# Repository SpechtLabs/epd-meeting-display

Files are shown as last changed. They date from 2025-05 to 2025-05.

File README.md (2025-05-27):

# ESP32 based E-Paper Meeting Room Display

If you work from home frequently and you have kids or a spouse working part-time you might find it difficult to signal if you're in a meeting right now or not.

While there might be "busy lights" available for purchase from Amazon to signal if you're available or not, I thought to myself "surely I could build that myself?".

And long and behold, my low-power meeting room display using a wifi-enabled ESP32 microcontroller and a 7.5" E-Paper display was born. It fetches Calendar data via [CalendarAPI](https://github.com/SpechtLabs/CalendarAPI) and not only prints an indicator if you're currently in a meeting or not, but it also shows a small overview of your schedule for the day, which I found super usefull. As soon as I enter my office, I already have an overview of my meeting schedule for the day.

The display also supports custom status messages and comes with an [HomeAssistant Integration](https://calendarapi.specht-labs.de/guide/home_assistant.html) so you can set custom status messages via HomeAssistant. In my case I use this if the resin 3D printer is running to display a biohazard icon and a status message reminding me of wearing a respirator.

## Credits

Huge thanks to [Luke Marzen](https://github.com/lmarzen) and his [ESP32 E-Paper Weather Display](https://github.com/lmarzen/esp32-weather-epd) project. It was a huge inspiration for me, and proved to be a very good starting point for me to base my display on.

## Required Components

| Component Type  | Component | Notes |
| --- | --- | --- |
| ESP32 | FireBeetle 2 ESP32-E | Features low-power design, USB-C, and battery management. |
| E-Paper Display | See [Panel Support](#panel-support). | See [Panel Support](#panel-support). |
| Adapter Board | DESPI-C02 | |
| Battery | 3.7V LiPo w/ JST-PH2.0 connector | Any capacity (e.g., 5000mAh for 6+ months runtime) |
| Enclosure | | See [Enclosure Options](#enclosure). |

Other items needed:

- Wires ("Jumper Wires" if looking to minimize/avoid soldering).
- Solder Iron + Solder
- Linux, Windows, or MacOS computer (used to configure and install ESP32 firmware).

### Panel Support

Refrain from using Waveshare Displays and jump straight to Good Display with a DESPI-C02 adapter board
Good Display make equivalent panels. Either variant will work.

| Panel | Resolution | Colors | Link |
| --- | --- | --- | --- |
| Good Display 7.5in e-paper (GDEY075T7) | 800x480px  | Black/White | [Good Display](https://www.good-display.com/product/396.html) |
| Good Display 7.5in e-paper (GDEY075Z08) | 800x480px  | Red/Black/White | [Good Display](https://www.good-display.com/product/394.html) |
| Good Display 7.3in e-paper (EOL) (GDEY073D46) | 800x480px  | 7-Color | [Good Display](https://www.good-display.com/product/442.html) |

This software has limited support for accent colors. E-paper panels with additional colors tend to have longer refresh times, which will reduce battery life.

### Enclosure

I designed a simple enclosure with a sliding mechanism in [OnShape](https://cad.onshape.com/documents/a085c42da6149c918189f270/w/8138a9f47d2dacfe28cef74e/e/b4459c145c0eb402d3061e76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). You can also download the [STL files here](./stl/).

Please feel free to improve on the enclosure and contribute improvements back.

## Setup Guide

### Wiring

> **Warning**
> The polarity of JST-PH2.0 connectors is not standardized! You may need to swap the order of the wires in the connector.

The battery can be charged by plugging the FireBeetle ESP32 into the wall via the USB-C connector while the battery is plugged into the ESP32's JST connector.

> **Important**
> The DESPI-C02 adapter has one physical switch that MUST be set correctly for the display to work.
>
> - RESE: Set switch to position 0.47.

Cut the low power pad for even longer battery life.

- From <https://wiki.dfrobot.com/FireBeetle_Board_ESP32_E_SKU_DFR0654>

  > Low Power Pad: This pad is specially designed for low power consumption. It is connected by default. You can cut off the thin wire in the middle with a knife to disconnect it. After disconnection, the static power consumption can be reduced by 500 μA. The power consumption can be reduced to 13 μA after controlling the maincontroller enter the sleep mode through the program. Note: when the pad is disconnected, you can only drive RGB LED light via the USB Power supply.

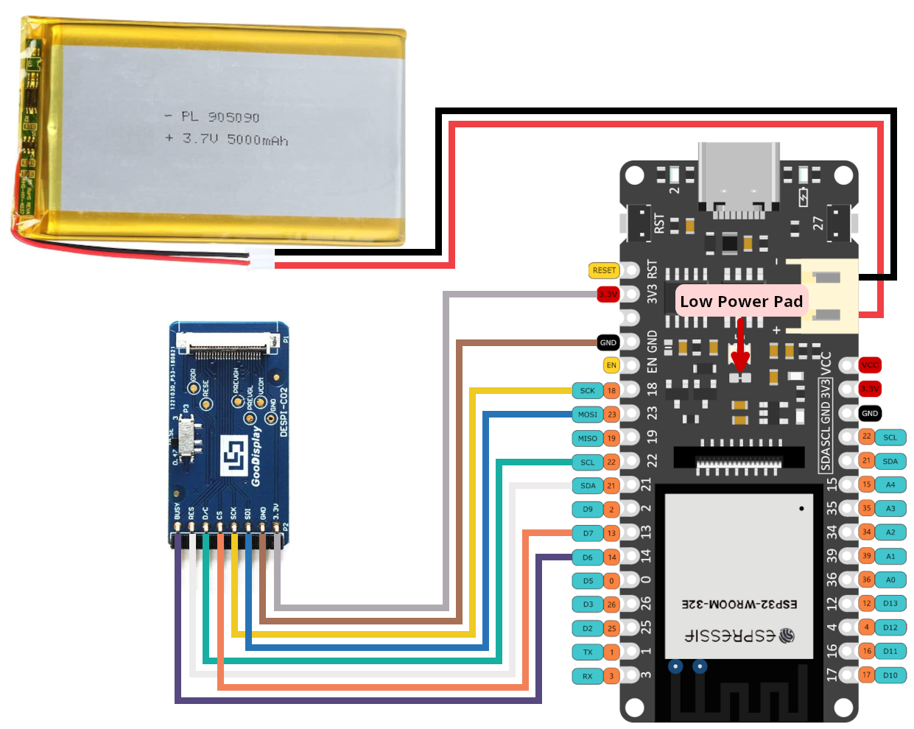
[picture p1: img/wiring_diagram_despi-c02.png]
Wiring diagram with DESPI-C02 driver board


### Configuration, Compilation, and Upload

[PlatformIO](https://platformio.org/) for VSCode is used for managing dependencies, code compilation, and uploading to ESP32.

1. Clone this repository or download and extract the `.zip`.
2. Install VSCode.
3. Follow [these instructions](https://platformio.org/install/ide?install=vscode) to install the PlatformIO extension for VSCode
4. Open the project in VSCode.
   1. `File` > `Open Folder...`
   2. Navigate to this project
5. Configure Options.
   - Configuration options are located in [config.h](include/config.h)
   - Important settings to configure in [config.h](include/config.h):
     - WiFi credentials (ssid, password)
     - [CalendarAPI](https://github.com/SpechtLabs/CalendarAPI) Endpoint
     - Timezone
     - Time and date formats
6. Build and Upload Code.
   1. Connect ESP32 to your computer via USB.
   2. Click the upload arrow along the bottom of the VSCode window. (Should say "PlatformIO: Upload" if you hover over it.)
      - PlatformIO will automatically download the required third-party libraries, compile, and upload the code. :)
      - You will only see this if you have the PlatformIO extension installed.
      - If using a FireBeetle 2 ESP32-E and you receive the error `Wrong boot mode detected (0x13)! The chip needs to be in download mode.` unplug the power from the board, connect GPIO0 ([labeled 0/D5](https://wiki.dfrobot.com/FireBeetle_Board_ESP32_E_SKU_DFR0654#target_5)) to GND, and power it back up to put the board in download mode.
      - If you are getting other errors during the upload process, you may need to install drivers to allow you to upload code to the ESP32.

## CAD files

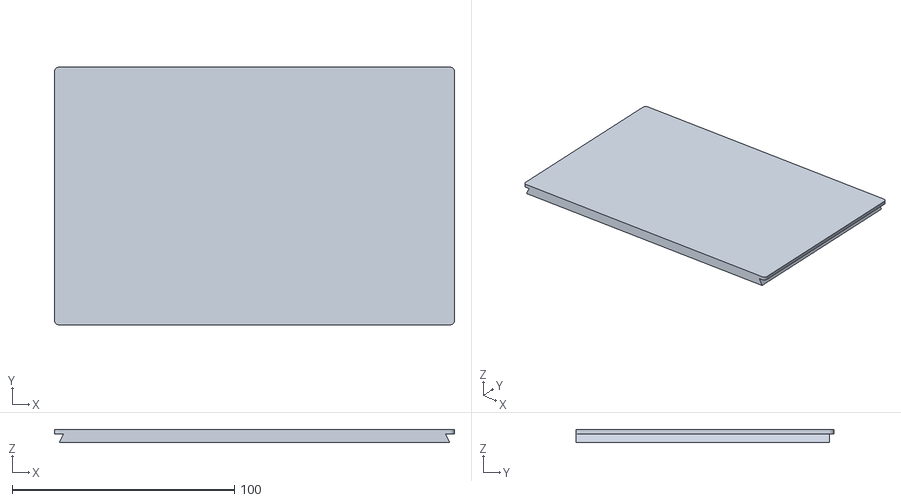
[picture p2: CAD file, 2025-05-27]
stl/backplate.stl
180.0 x 116.0 x 6.00

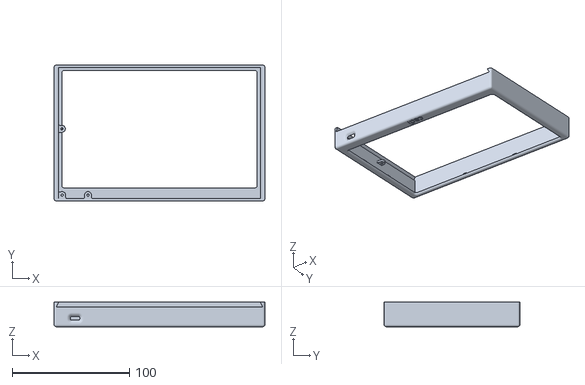
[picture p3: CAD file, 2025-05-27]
stl/case.stl
180.0 x 116.0 x 21.0

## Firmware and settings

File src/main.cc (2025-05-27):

#include <Arduino.h>
#include <Preferences.h>
#include <time.h>
#include <WiFi.h>
#include <WiFiClient.h>
#include <Wire.h>
#include <ctime>
#include <string>
#include <sstream>

#include "config.h"
#include "utils.h"
#include "client/calendar_client.h"
#include "components/display_config.h"

#include "display.h"

Preferences prefs;
calendar_client::CalendarClient calClient(API_ENDPOINT, API_ENDPOINT_PORT);

#if defined(DISP_3C) || defined(DISP_7C)
Display epd(PIN_EPD_PWR, PIN_EPD_SCK, PIN_EPD_MISO, PIN_EPD_MOSI, PIN_EPD_CS, PIN_EPD_DC, PIN_EPD_RST, PIN_EPD_BUSY, &calClient, ACCENT_COLOR);
#else
Display epd(PIN_EPD_PWR, PIN_EPD_SCK, PIN_EPD_MISO, PIN_EPD_MOSI, PIN_EPD_CS, PIN_EPD_DC, PIN_EPD_RST, PIN_EPD_BUSY, &calClient);
#endif

// Put esp32 into ultra low-power deep sleep (<11μA).
void beginDeepSleep(unsigned long startTime)
{
	killWiFi();

	tm timeInfo = {};
	// only call getLocalTime if we havent gotten the ntp time yet
	if (!getLocalTime(&timeInfo))
	{
		Serial.println("Failed to synchronize time before deep-sleep, referencing older time.");
	}

	time_t now = mktime(&timeInfo);

	int sleepSeconds = SLEEP_DURATION * 60; // SLEEP_DURATION is in minutes, multiply by 60

	// Sleep duration is until the end of this meeting, or till the beginning of the next meeting
	const calendar_client::CalendarEntry *currEvent = calClient.getCurrentEvent(now, false);

	if (currEvent != NULL)
	{
		sleepSeconds = difftime(currEvent->getEnd(), now); // calculate the minutes until the event ends
#if DEBUG_LEVEL >= 1
		Serial.println("[debug] sleeping till end of this event: " + currEvent->getTitle() + " (" + sleepSeconds + "s)");
#endif
	}
	else
	{
		const calendar_client::CalendarEntry *nextEvent = calClient.getNextEvent(now);
		if (nextEvent != NULL)
		{
			sleepSeconds = difftime(nextEvent->getStart(), now); // calculate the minutes until the next event starts
#if DEBUG_LEVEL >= 1
			Serial.println("[debug] sleeping till start of next event: " + nextEvent->getTitle() + " (" + sleepSeconds + "s)");
#endif
		}
	}

	// if we sleep for more than SLEEP_DURATION, wake up a bit earlier,
	// to check for potential new calendar invites
	if (sleepSeconds > SLEEP_DURATION * 60)
	{
		sleepSeconds = SLEEP_DURATION * 60;
	}

	// add extra delay to compensate for esp32's with fast RTCs.
	sleepSeconds += 10ULL;

#if DEBUG_LEVEL >= 1
	printHeapUsage();
#endif

	Serial.println("\nAwake for " + String((millis() - startTime) / 1000.0, 3) + "s");
	Serial.println("Entering deep sleep for " + String(sleepSeconds) + "s");
	esp_sleep_enable_timer_wakeup(sleepSeconds * 1000000ULL);

	esp_deep_sleep_start();
}

// Program entry point.
void setup()
{
	unsigned long startTime = millis();
	Serial.begin(115200);

#if DEBUG_LEVEL >= 1
	printHeapUsage();
#endif

	disableBuiltinLED();

	// Open namespace for read/write to non-volatile storage
	prefs.begin(NVS_NAMESPACE, false);

	uint32_t batteryVoltage = readBatteryVoltage();
	Serial.print("Battery voltage");
	Serial.println(": " + String(batteryVoltage) + "mv");

	// When the battery is low, the display should be updated to reflect that, but
	// only the first time we detect low voltage. The next time the display will
	// refresh is when voltage is no longer low. To keep track of that we will
	// make use of non-volatile storage.
	bool lowBat = prefs.getBool("lowBat", false);

	// low battery, deep sleep now
	if (batteryVoltage <= LOW_BATTERY_VOLTAGE)
	{
		if (lowBat == false)
		{ // battery is now low for the first time
			prefs.putBool("lowBat", true);
			prefs.end();
			epd.error("battery_alert_90deg", "Low Battery");
		}

		// critically low battery
		// don't set esp_sleep_enable_timer_wakeup();
		// We won't wake up again until someone manually presses the RST button.
		if (batteryVoltage <= CRIT_LOW_BATTERY_VOLTAGE)
		{
			Serial.println("Critically low battery voltage!");
			Serial.println("Hibernating without wake time!");
		}
		// very low battery
		else if (batteryVoltage <= VERY_LOW_BATTERY_VOLTAGE)
		{
			Serial.println("Very low battery voltage!");
			Serial.print("Entering deep sleep for " + String(VERY_LOW_BATTERY_SLEEP_INTERVAL) + "min");
			esp_sleep_enable_timer_wakeup(VERY_LOW_BATTERY_SLEEP_INTERVAL * 60ULL * 1000000ULL);
		}
		// low battery
		else
		{
			Serial.println("Low battery voltage!");
			Serial.println("Entering deep sleep for " + String(LOW_BATTERY_SLEEP_INTERVAL) + "min");
			esp_sleep_enable_timer_wakeup(LOW_BATTERY_SLEEP_INTERVAL * 60ULL * 1000000ULL);
		}

		esp_deep_sleep_start();
	}

	// battery is no longer low, reset variable in non-volatile storage
	if (lowBat == true)
	{
		prefs.putBool("lowBat", false);
	}

	// All data should have been loaded from NVS. Close filesystem.
	prefs.end();

	tm timeInfo = {};

	// START WIFI
	wl_status_t wifiStatus = startWiFi();

	// WiFi Connection Failed
	if (wifiStatus != WL_CONNECTED)
	{

		if (wifiStatus == WL_NO_SSID_AVAIL)
		{
			epd.error("wifi_x", "Network Not Available");
		}
		else
		{
			epd.error("wifi_x", "WiFi Connection Failed");
		}

		beginDeepSleep(startTime);
	}

	// TIME SYNCHRONIZATION
	configTzTime(TIMEZONE, NTP_SERVER_1, NTP_SERVER_2);
	bool timeConfigured = getNtpTime(&timeInfo);
	if (!timeConfigured)
	{
		epd.error("wi_time_4", "Time Synchronization Failed");
		beginDeepSleep(startTime);
	}

	int httpStatus = calClient.fetchCustomStatus();
	if (httpStatus != HTTP_CODE_OK && httpStatus != HTTP_CODE_GONE)
	{
		std::stringstream ss;
		ss << "Fetching status failed";

		epd.error("wi_cloud_down", ss.str().c_str(), calendar_client::CalendarClient::getHttpResponsePhrase(httpStatus), mktime(&timeInfo));
		beginDeepSleep(startTime);
	}

	const calendar_client::CustomStatus *stat = calClient.getCustomStatus();
	if (stat != NULL && !stat->getTitle().isEmpty())
	{
		epd.fullPageStatus(stat->getIcon(), stat->getIconSize(), stat->getTitle(), stat->getDescription(), mktime(&timeInfo));
		beginDeepSleep(startTime);
	}

	httpStatus = calClient.fetchCalendar();
	if (httpStatus != HTTP_CODE_OK && httpStatus != HTTP_CODE_GONE)
	{
		std::stringstream ss;
		ss << "Fetching calendar failed";

		epd.error("wi_cloud_down", ss.str().c_str(), calendar_client::CalendarClient::getHttpResponsePhrase(httpStatus), mktime(&timeInfo));
		beginDeepSleep(startTime);
	}

	epd.render(mktime(&timeInfo));
	beginDeepSleep(startTime);
}

// This will never run
void loop()
{
}

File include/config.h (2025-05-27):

#pragma once

// WIFI
#define WIFI_SSID "<your_wifi_ssid>"
#define WIFI_PASSWORD "<your_wifi_password>"

// API
#define API_ENDPOINT "<your_api_endpoint>" // e.g. "homeassistant.local"
#define API_ENDPOINT_PORT 8099
#define API_ENDPOINT_FETCH_CALENDAR "<your_calendar_name>" // e.g. "work" or "home" or "all" to fetch all calendars

// Sleep duration in minutes. (aka how often esp32 will wake for an update)
#define SLEEP_DURATION 15 // minutes

// Display Strings
// This is usefull for localization and translation.
// If you want to change the language, you can do so by changing the
// TXT_... defines below.
#define TXT_PAST_EVENTS "past events"
#define TXT_UPCOMING_EVENTS "upcoming events"
#define TXT_UNTIL "until"
#define TXT_FREE "free"

// E-PAPER PANEL
// This project supports the following E-Paper panels:
//   DISP_BW  - 7.5in e-Paper (v2)      800x480px  Black/White
//   DISP_3C  - 7.5in e-Paper (B)       800x480px  Red/Black/White
//   DISP_7C  - 7.3in ACeP e-Paper (F)  800x480px  7-Color
// Uncomment the macro that identifies your physical panel.
#define DISP_BW
// #define DISP_3C
// #define DISP_7C

// DEBUG
//   If defined, enables increase verbosity over the serial port.
//   level 0: basic status information, assists troubleshooting (default)
//   level 1: increased verbosity for debugging
//   level 2: print api responses and verbose info to serial monitor
//   level 3: print display_buffer drawings (very noisy)
//   level 4: draw boundaries on draws
#define DEBUG_LEVEL 1

// TIME
// For list of time zones see
// https://github.com/nayarsystems/posix_tz_db/blob/master/zones.csv
#define TIMEZONE "CET-1CEST,M3.5.0,M10.5.0/3"

// Time format used when displaying sunrise/set times. (Max 11 characters)
// For more information about formatting see
// https://man7.org/linux/man-pages/man3/strftime.3.html
#define TIME_FORMAT "%H:%M" // 24-hour ex: 01:23   23:00

// Time format used when displaying axis labels. (Max 11 characters)
// For more information about formatting see
// https://man7.org/linux/man-pages/man3/strftime.3.html
#define HOUR_FORMAT "%H" // 24-hour ex: 01   23

// Date format used when displaying date in top-right corner.
// For more information about formatting see
// https://man7.org/linux/man-pages/man3/strftime.3.html
#define DATE_FORMAT "%a, %B %e" // ex: Sat, January 1

// Date/Time format used when displaying the last refresh time along the bottom
// of the screen.
// For more information about formatting see
// https://man7.org/linux/man-pages/man3/strftime.3.html
#define REFRESH_TIME_FORMAT "%e.%m.%Y %H:%M"

// NON-VOLATILE STORAGE (NVS) NAMESPACE
#define NVS_NAMESPACE "meeting_epd"

#ifdef DISP_BW
#define INVERT_AS_ACCENT true
#else
#define INVERT_AS_ACCENT false
#define ACCENT_COLOR Color::Red
#endif

// PINS
// The configuration below is intended for use with the project's official
// wiring diagrams using the FireBeetle 2 ESP32-E microcontroller board.
//
// Note: LED_BUILTIN pin will be disabled to reduce power draw.  Refer to your
//       board's pinout to ensure you avoid using a pin with this shared
//       functionality.
//
// ADC pin used to measure battery voltage
#define PIN_BAT_ADC A2 // A0 for micro-usb firebeetle

// Pins for E-Paper Driver Board
#define PIN_EPD_BUSY 14 // 5 for micro-usb firebeetle
#define PIN_EPD_CS 13
#define PIN_EPD_RST 21
#define PIN_EPD_DC 22
#define PIN_EPD_SCK 18
#define PIN_EPD_MISO 19 // 19 Master-In Slave-Out not used, as no data from display
#define PIN_EPD_MOSI 23
#define PIN_EPD_PWR 26 // Irrelevant if directly connected to 3.3V

// HTTP
// The following errors are likely the result of insuffient http client tcp timeout:
//   -1   Connection Refused
//   -11  Read Timeout
//   -258 Deserialization Incomplete Input
#define HTTP_CLIENT_TCP_TIMEOUT 1000 // ms

// ms, WiFi connection timeout.
#define WIFI_TIMEOUT 10000
// Number of times to retry connecting to WiFi or fetching the API before giving up.
#define RETRY_COUNT 10

// NTP_SERVER_1 is the primary time server, while NTP_SERVER_2 is a fallback.
// pool.ntp.org will find the closest available NTP server to you.
#define NTP_SERVER_1 "pool.ntp.org"
#define NTP_SERVER_2 "time.nist.gov"

// If you encounter the 'Failed To Fetch The Time' error, try increasing
// NTP_TIMEOUT or select closer/lower latency time servers.
#define NTP_TIMEOUT 20000 // ms
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

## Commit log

2026-10-08 chore(deps): update dependency jdx/mise to v2026.10.4 (#19)
    This PR contains the following updates:
    | Package | Update | Change | Pending |
    |---|---|---|---|
    | [jdx/mise](https://redirect.github.com/jdx/mise) | patch | `2026.10.3`
    → `2026.10.4` | `2026.10.5` |
    ---
    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
2026-10-10 chore(deps): update dependency jdx/mise to v2026.10.5 (#22)
    | [jdx/mise](https://redirect.github.com/jdx/mise) | patch | `2026.10.4`
    → `2026.10.5` | `2026.10.7` (+1) |
    ### Release Notes
    <details>
    <summary>jdx/mise (jdx/mise)</summary>
    ###
    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
2026-10-10 chore(deps): update dependency python to v3.15.0 (#21)
    | Package | Type | Update | Change |
    | [python](https://redirect.github.com/python/cpython) | tools | minor |
    `3.14.8` → `3.15.0` |
    <summary>python/cpython (python)</summary>
    [`v3.15.0`](https://redirect.github.com/python/cpython/compare/v3.14.8...v3.15.0rc2)
    [Compare
    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
2026-10-10 chore(deps): update dependency jdx/mise to v2026.10.6 (#24)
    | [jdx/mise](https://redirect.github.com/jdx/mise) | patch | `2026.10.5`
    → `2026.10.6` | `2026.10.7` |
    [`v2026.10.6`](https://redirect.github.com/jdx/mise/blob/HEAD/CHANGELOG.md#2026106---2026-10-09)
    Source](https://redirect.github.com/jdx/mise/compare/vfox-v2026.10.5...vfox-v2026.10.6)
    ##### 🚀 Features
    - **(bootstrap)** offer to install git and ssh before cloning a
    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
2026-10-11 chore(deps): update dependency jdx/mise to v2026.10.7 (#25)
    | Package | Update | Change |
    |---|---|---|
    | [jdx/mise](https://redirect.github.com/jdx/mise) | patch | `2026.10.6`
    → `2026.10.7` |
    [`v2026.10.7`](https://redirect.github.com/jdx/mise/blob/HEAD/CHANGELOG.md#2026107---2026-10-09)
    Source](https://redirect.github.com/jdx/mise/compare/vfox-v2026.10.6...vfox-v2026.10.7)
    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
2026-10-13 chore(deps): update dependency jdx/mise to v2026.10.8 (#26)
    | [jdx/mise](https://redirect.github.com/jdx/mise) | patch | `2026.10.7`
    → `2026.10.8` |
    [`v2026.10.8`](https://redirect.github.com/jdx/mise/blob/HEAD/CHANGELOG.md#2026108---2026-10-11)
    Source](https://redirect.github.com/jdx/mise/compare/vfox-v2026.10.7...vfox-v2026.10.8)
    - **(runtime-symlinks)** add a global link to the version global config
    selects by [@&#8203;jdx](https://redirect.github.com/jdx) in
    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
2026-10-14 chore(deps): update dependency jdx/mise to v2026.10.9 (#29)
    | [jdx/mise](https://redirect.github.com/jdx/mise) | patch | `2026.10.8`
    → `2026.10.9` | `2026.10.10` |
    <summary>jdx/mise</summary>
    [`v2026.10.9`](https://redirect.github.com/jdx/mise/blob/HEAD/CHANGELOG.md#2026109---2026-10-13)
    Source](https://redirect.github.com/jdx/mise/compare/vfox-v2026.10.8...vfox-v2026.10.9)
    - **(bootstrap)** add apt repositories and PPAs with
    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
2026-10-15 chore(deps): update dependency jdx/mise to v2026.10.10 (#30)
    | [jdx/mise](https://redirect.github.com/jdx/mise) | patch | `2026.10.9`
    → `2026.10.10` | `2026.10.11` |
    [`v2026.10.10`](https://redirect.github.com/jdx/mise/blob/HEAD/CHANGELOG.md#20261010---2026-10-14)
    Source](https://redirect.github.com/jdx/mise/compare/vfox-v2026.10.9...vfox-v2026.10.10)
    - **(bootstrap)** add snap package manager by
    [@&#8203;jdx](https://redirect.github.com/jdx) in
    [#&#8203;14402](https://redirect.github.com/jdx/m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
2026-10-16 chore(deps): update dependency jdx/mise to v2026.10.11 (#31)
    | [jdx/mise](https://redirect.github.com/jdx/mise) | patch |
    `2026.10.10` → `2026.10.11` |
    [`v2026.10.11`](https://redirect.github.com/jdx/mise/blob/HEAD/CHANGELOG.md#20261011---2026-10-15)
    Source](https://redirect.github.com/jdx/mise/compare/vfox-v2026.10.10...vfox-v2026.10.11)
    - **(bootstrap)** add --upgrade to upgrade packages and tools by
    [#&#8203;14433](https://redirect.github.com/jdx/mise/pull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
2026-10-18 chore(deps): update dependency jdx/mise to v2026.10.12 (#33)
    `2026.10.11` → `2026.10.12` | `2026.10.13` |
    [`v2026.10.12`](https://redirect.github.com/jdx/mise/blob/HEAD/CHANGELOG.md#20261012---2026-10-16)
    Source](https://redirect.github.com/jdx/mise/compare/vfox-v2026.10.11...vfox-v2026.10.12)
    - **(config)** add find_up option to env.\_.file by
    [#&#8203;14497](https://redirect.github.c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
2026-10-19 chore(deps): update dependency jdx/mise to v2026.10.13 (#34)
    `2026.10.12` → `2026.10.13` | `2026.10.14` |
    [`v2026.10.13`](https://redirect.github.com/jdx/mise/blob/HEAD/CHANGELOG.md#20261013---2026-10-17)
    Source](https://redirect.github.com/jdx/mise/compare/vfox-v2026.10.12...vfox-v2026.10.13)
    - **(bootstrap)** template repo url and ref, add clone options by
    [#&#8203;14548](https://red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
2026-10-20 chore(deps): update dependency jdx/mise to v2026.10.15 (#36)
    `2026.10.13` → `2026.10.15` |
    [`v2026.10.15`](https://redirect.github.com/jdx/mise/blob/HEAD/CHANGELOG.md#20261015---2026-10-19)
    Source](https://redirect.github.com/jdx/mise/compare/vfox-v2026.10.14...vfox-v2026.10.15)
    - **(backend)** serve every backend's version list from the versions
    host by [@&#8203;jdx](https://redirect.github.com/jdx) in
    [#&#8203;14700](https://redirect.github.com/j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
2026-10-25 chore(deps): update dependency pinact to v5.0.2 (#45)
    | [pinact](https://redirect.github.com/suzuki-shunsuke/pinact) | tools |
    patch | `5.0.1` → `5.0.2` |
    <summary>suzuki-shunsuke/pinact (pinact)</summary>
    [`v5.0.2`](https://redirect.github.com/suzuki-shunsuke/pinact/releases/tag/v5.0.2)
    Source](https://redirect.github.com/suzuki-shunsuke/pinact/compare/v5.0.1...v5.0.2)
    [#&#8203;1813](https://redirect.github.com/suzuki-shunsuke/pinact/issues/1813)
    Publish packslip.sigstore.json
    📅 **Schedule**: (in timezon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
2026-11-06 chore(deps): update dependency jdx/mise to v2026.11.2 (#61)
    | [jdx/mise](https://redirect.github.com/jdx/mise) | patch | `2026.11.1`
    → `2026.11.2` | `2026.11.3` |
    [`v2026.11.2`](https://redirect.github.com/jdx/mise/blob/HEAD/CHANGELOG.md#2026112---2026-11-05)
    Source](https://redirect.github.com/jdx/mise/compare/v2026.11.1...v2026.11.2)
    - **(task)** add a summary output style that prints only what failed by
    [#&#8203;15403](https://redirect.github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
2026-11-13 chore(deps): update dependency jdx/mise to v2026.11.7 (#69)
    | [jdx/mise](https://redirect.github.com/jdx/mise) | patch | `2026.11.6`
    → `2026.11.7` |
    [`v2026.11.7`](https://redirect.github.com/jdx/mise/blob/HEAD/CHANGELOG.md#2026117---2026-11-11)
    Source](https://redirect.github.com/jdx/mise/compare/vfox-v2026.11.6...vfox-v2026.11.7)
    - **(shim)** one-line no-version error and opt-in
    shims.fallback_to_installed by
    [#&#8203;15525](https://redirect.github.com/jdx/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
